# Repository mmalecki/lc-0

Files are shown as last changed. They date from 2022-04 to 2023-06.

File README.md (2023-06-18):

# Launch Controller 0

Simple switch-based model rocket launcher. When I say simple, I mean it!

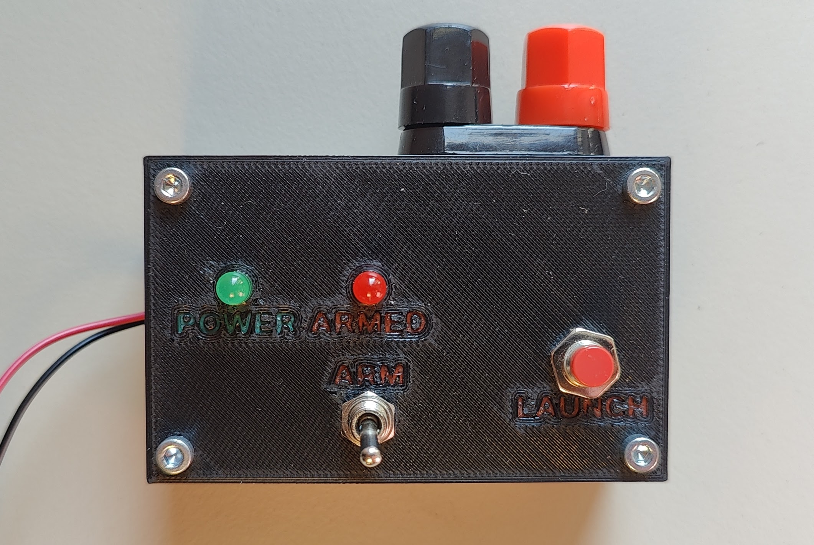
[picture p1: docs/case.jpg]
Case


Continuity checking? Yeah, sure, I'll tell you I've heard about it.

Keyed arm switch? Right, as if I had any keys laying around doing NOTHING.

I mean, frankly, the thing doesn't even have space for batteries in its enclosure.

On the other hand, its most complicated components is probably the LED telling
you the launcher is receiving power. (What, were you hoping for a switch?)

You can load a larger capacitor in there to fire a cluster of rockets with a 9 V
battery, and the 2 mm traces should withstand about anything.

## Building
First, clone this repository:
```sh
git clone https://github.com/mmalecki/lc-0
cd lc-0
git submodule update --init
```

1. Open the KiCAD project in the `electronics` directory. Get the PCB made (one-sided
is all that's needed here).
2. Render and 3D print the files in `enclosure`.

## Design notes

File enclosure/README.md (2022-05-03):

# Enclosure
The LC-0 enclosure is built in OpenSCAD.

To see a mockup, open `enclosure.scad`.

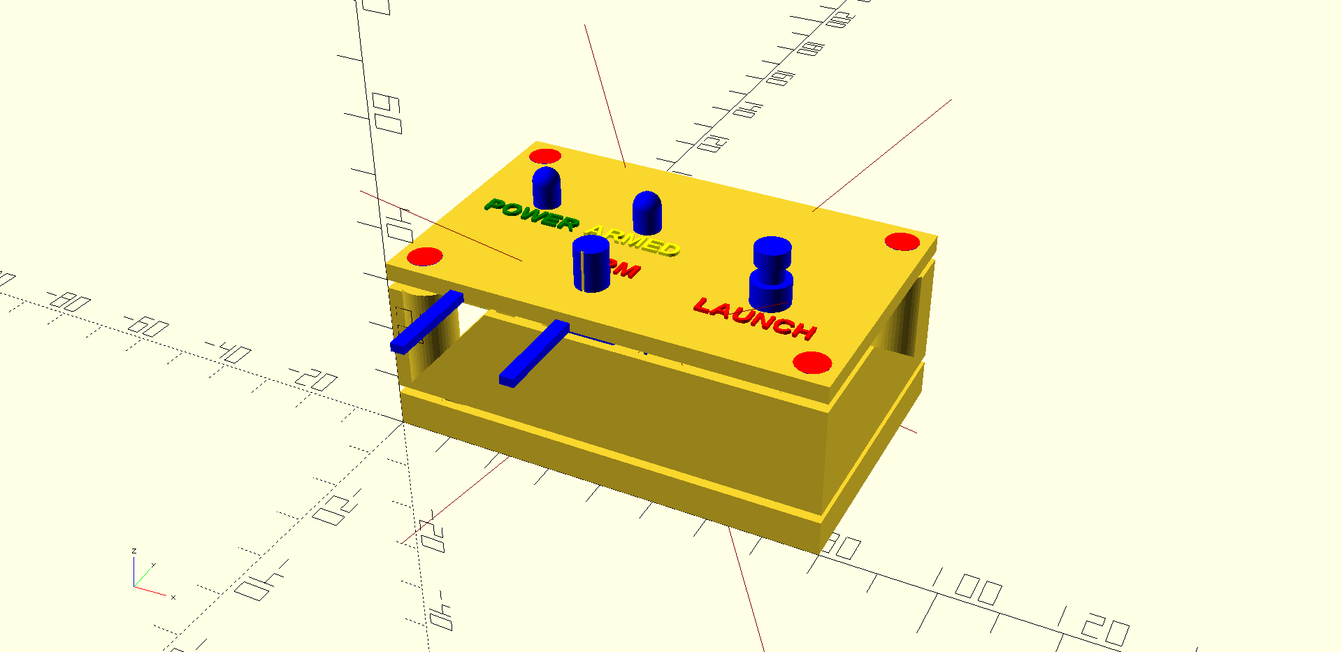
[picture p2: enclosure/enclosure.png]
Enclosure mockup


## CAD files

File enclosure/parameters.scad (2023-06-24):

$fn = 50;

w = 80;
l = 50;
h = 30;
thickness = 1.6;

panel_margin_bottom = 10;
panel_margin_left = 14;
text_size = 3.5;
text_emboss_d = 0.2;

screw_size = "M3";
screw_l = 30;

pcb_mount_w = 55.88;
pcb_mount_l = 22.352;
pcb_mount_screw_l = 8;
pcb_thickness = 1.55;
pcb_standoff_d = 7.5;

standoff_height = 2;
standoff_d = 9.5;

banana_plug_mount_x = 7 / 10 * w;
banana_plug_mount_z = 1 / 2 * h;
banana_plug_mount_d = 4.75;
banana_plug_mount_distance = 18.98;

power_cable_w = 2;
power_cable_h = 3;

bottom_height = thickness + standoff_height;
body_height = h - bottom_height - 2 * thickness;

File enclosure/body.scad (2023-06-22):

include <mounts.scad>;
include <parameters.scad>;

e = 0.001;

module body (w, l, h, thickness) {
  difference() {
    linear_extrude(h) {
      difference() {
        square([ w, l ]);
        translate([ thickness, thickness ])
          square([ w - 2 * thickness, l - 2 * thickness ]);
      }
    }

    translate([ banana_plug_mount_x, l, banana_plug_mount_z ]) {
      rotate([ 90, 0, 0 ]) {
        translate([ -banana_plug_mount_distance / 2, 0, 0 ])
          cylinder(d = banana_plug_mount_d, h = thickness + e);

        translate([ banana_plug_mount_distance / 2, 0, 0 ])
          cylinder(d = banana_plug_mount_d, h = thickness + e);
      }
    }

    translate([ 0, (l - power_cable_w) / 2, 0 ]) {
      cube([ thickness, power_cable_w, power_cable_h ]);
    }
  }

  translate([ standoff_d / 2, standoff_d / 2, 0 ]) {
    rect_mounting_bracket(w - standoff_d, l - standoff_d, standoff_d, h, screw_size);
  }
}

body(w, l, body_height, thickness);

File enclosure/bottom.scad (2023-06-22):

include <parameters.scad>;
use <catchnhole/catchnhole.scad>
use <mounts.scad>;

module bottom (w, l, thickness, standoff_height) {
  difference() {
    cube([ w, l, thickness ]);
    translate([ standoff_d / 2, standoff_d / 2, 0 ]) {
      rect(w - standoff_d, l - standoff_d) {
        nutcatch_parallel(screw_size);
        bolt(screw_size, length = standoff_height);
      }
    }
    translate([ (w - pcb_mount_w) / 2, (l - pcb_mount_l) / 2, 0 ]) {
      rect(pcb_mount_w, pcb_mount_l) {
        nutcatch_parallel(screw_size);
        bolt(screw_size, length = standoff_height);
      }
    }
  }

  translate([ 0, 0, thickness ]) {
    linear_extrude(standoff_height) {
      difference() {
        square([ w, l ]);
        translate([ thickness, thickness ])
          square([ w - 2 * thickness, l - 2 * thickness ]);
      }
    }

    translate([ standoff_d / 2, standoff_d / 2, 0 ]) {
      rect_mounting_bracket(
        w - standoff_d, l - standoff_d, standoff_d, standoff_height, screw_size
      );
    }

    translate([ (w - pcb_mount_w) / 2, (l - pcb_mount_l) / 2, 0 ]) {
      rect(pcb_mount_w, pcb_mount_l) {
        standoff(pcb_standoff_d, standoff_height, screw_size);
      }
    }
  }
}

bottom(w, l, thickness, standoff_height);

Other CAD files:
enclosure/enclosure.scad
enclosure/mounts.scad
enclosure/panel.scad

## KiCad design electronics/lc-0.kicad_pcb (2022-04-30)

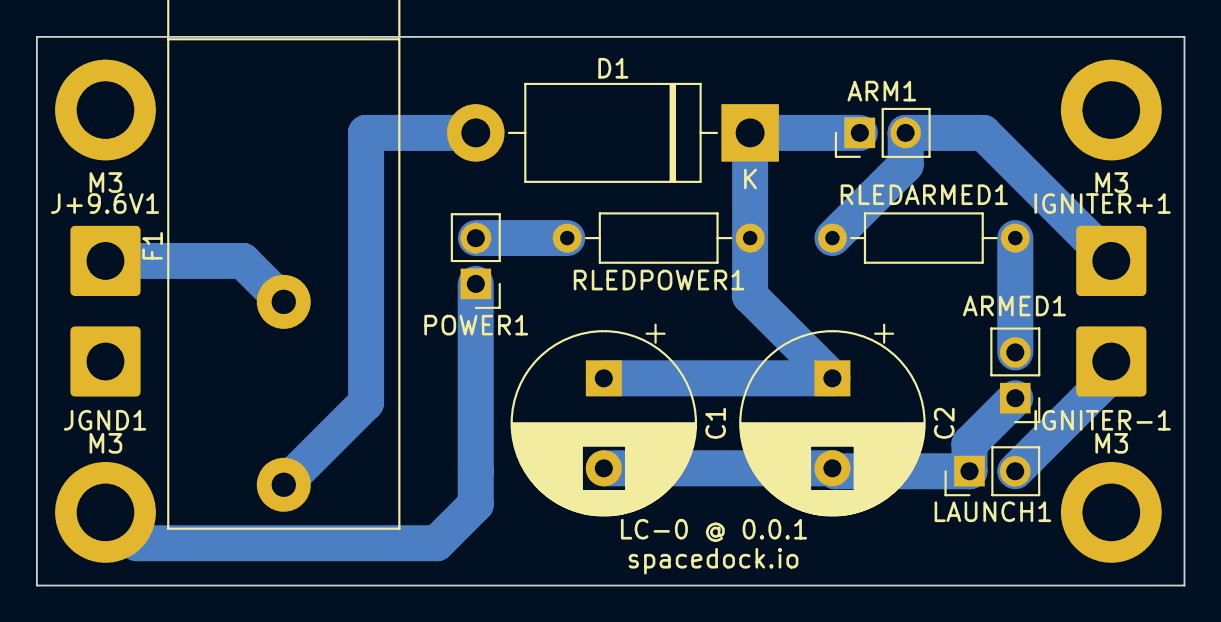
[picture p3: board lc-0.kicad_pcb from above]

Board: 2 copper layers, 63.8 x 30.5 mm, 18 parts (0 on the bottom side), 8 nets.

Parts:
ARM1: SW_SPST; PinHeader_1x02_P2.54mm_Vertical
ARMED1: LED; PinHeader_1x02_P2.54mm_Vertical
C1, C2: 470 uF; CP_Radial_D10.0mm_P5.00mm
D1: D_Schottky; D_DO-201AD_P15.24mm_Horizontal
F1: Fuse; Fuseholder_Cylinder-5x20mm_Bulgin_FX0457_Horizontal_Closed
IGNITER+1: Conn_01x01; SolderWire-1.5sqmm_1x01_D1.7mm_OD3.9mm
IGNITER-1: Conn_01x01; SolderWire-1.5sqmm_1x01_D1.7mm_OD3.9mm
J+9.6V1: Conn_01x01; SolderWire-1.5sqmm_1x01_D1.7mm_OD3.9mm
JGND1: Conn_01x01; SolderWire-1.5sqmm_1x01_D1.7mm_OD3.9mm
LAUNCH1: SW_Push; PinHeader_1x02_P2.54mm_Vertical
M3, M3#2, M3#3, M3#4: MountingHole_3.2mm_M3_DIN965_Pad
POWER1: LED; PinHeader_1x02_P2.54mm_Vertical
RLEDARMED1: 360; R_Axial_DIN0207_L6.3mm_D2.5mm_P10.16mm_Horizontal
RLEDPOWER1: 360; R_Axial_DIN0207_L6.3mm_D2.5mm_P10.16mm_Horizontal

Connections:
GND: ARMED1.1 (K), C1.2, C2.2, JGND1.1, LAUNCH1.1, M3.1, M3#2.1, M3#3.1, M3#4.1, POWER1.1 (K)
unnamed: ARM1.1 (A), C1.1, C2.1, D1.1 (K), RLEDPOWER1.1
unnamed: ARM1.2 (B), IGNITER+1.1, RLEDARMED1.1
unnamed: ARMED1.2 (A), RLEDARMED1.2
unnamed: D1.2 (A), F1.1
unnamed: IGNITER-1.1, LAUNCH1.2
unnamed: POWER1.2 (A), RLEDPOWER1.2
VCC: F1.2, J+9.6V1.1

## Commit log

2022-04-30 Add electronics, v0.0.1
    [lc-0.kicad_pcb, lc-0.kicad_sch]
2022-05-01 Add enclosure dependencies
2022-05-03 Add an enclosure
    [body.scad, bottom.scad, enclosure.scad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]
2022-05-10 Update `push-switches`
2022-05-10 Move the launch button and texts a little
    [enclosure.scad]
2023-02-13 Add a picture of the case
2023-06-22 Clean up the nutcatches
    Emboss the text instead.
    [body.scad, bottom.scad, enclosure.scad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]
2023-06-23 Let's give up on calculating the height of this
    Use M3x35's. We're short a `t`.
    This is probably the last comment here. The next one will be much more
    overengineered.
    [mounts.scad, panel.scad, parameters.scad]
2023-06-24 Fix body height calculation
    Warning: this will likely remain untested.
    [parameters.scad]
